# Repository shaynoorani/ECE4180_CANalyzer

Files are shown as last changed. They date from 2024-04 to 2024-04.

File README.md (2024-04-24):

# CANalyzer - Frugal CAN Line Analyzer with a C# GUI
- Brendan Bassett, Carl Cort, Eric Galluzi, Shayan Noorani, Tiancheng Zhao
- Throughout this page, there are links to the section of the main github repo [shaynoorani/ECE4180_CANalyzer](https://github.com/shaynoorani/ECE4180_CANalyzer/tree/main/functionaloverview.png) that correspond to the given component. Navigate to those to see the exact implementations

Team Picture

## Description
- CAN Line Analyzer for easy access to CAN data
- Simple C#-based GUI
   - Can filter based on CAN message ID
- Calculates and displays CAN Load

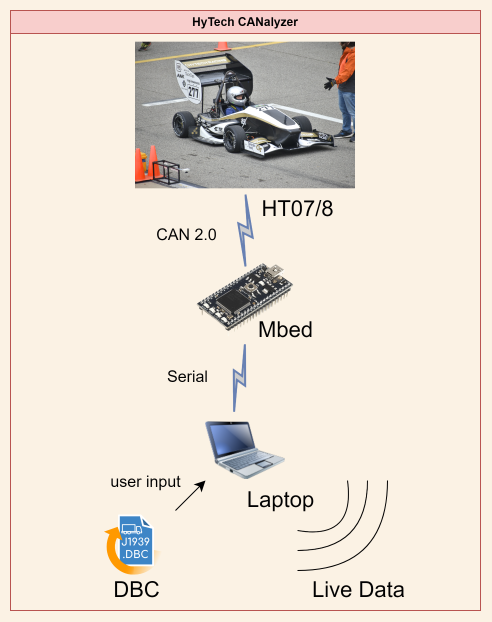
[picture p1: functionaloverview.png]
Team Picture


## Functionality Demo
[Team Picture](https://youtu.be/kEs1tA9cYeo?si=FgBFabkiXCYflOZx)

## Hardware
### Parts
- (x1) [Mbed](https://www.nxp.com/products/processors-and-microcontrollers/arm-microcontrollers/general-purpose-mcus/lpc1700-arm-cortex-m3/arm-mbed-lpc1768-board:OM11043)
- (x1) [CAN Transducer](https://www.trustedparts.com/en/part/texas-instruments/TCAN1051HDRQ1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)
- (x1) [SOP14 SMD-to-DIP Breakout](https://pmdway.com/products/sop14-tssop14-to-dip-adaptor-pcbs-10-pack)
  - Simply used as a breakout for the CAN Transducer for use on a breadboard
- [Breadboard](https://www.digikey.com/en/products/detail/universal-solder-electronics-ltd/SOLDERLESS%2520BREADBOARD%2520400/16819785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)
- Housing (optional)
- Male Molex Connector (optional)

### [Electronics](https://github.com/shaynoorani/ECE4180_CANalyzer/tree/main/schematic)

#### Wiring Diagram
Wiring Diagram

Note: the TCAN105 is the SMD CAN transducer itself and the wiring shown is for that device. However, the wires directly from the mbed go through the SOP14 breakout. The maping for the TCAN105 pins to the SOP14 pins are TCAN105(1-4) -> SOP14(1-4) and TCAN105(5-8) -> SOP14(11-14). This can be seen in the realworld image below.

#### Closeup of the Electronics
Closeup of the final electronics

### [Housing](https://github.com/shaynoorani/ECE4180_CANalyzer/tree/main/Housing) (Optional)
- The housing was developed to make the device more rugged for practical use but is not required for functionality
- As such, this section is presented to show not only our final design but also the measurements of the underlying device so that a different housing ould be developed if desired

#### Embedded Device Dimensions
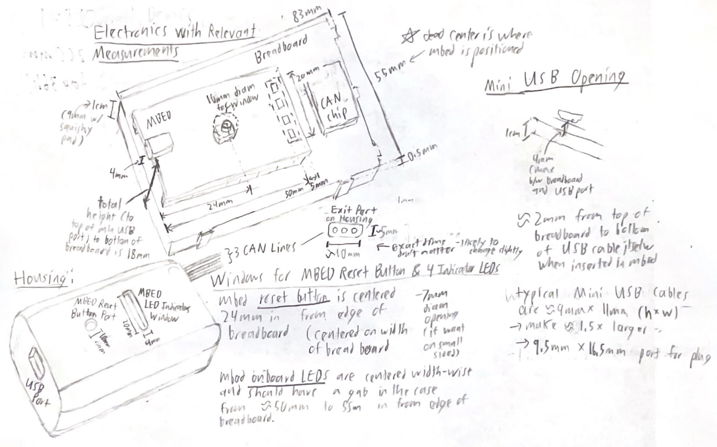
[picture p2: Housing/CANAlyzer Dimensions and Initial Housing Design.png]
Dimensions of relavent parts of the embedded device for designing the housing


*The CAN lines no longer come out as 3 lines but as one bundled wire that are terminated with a male molex connector since our car's CAN was accessible via a female molex

#### Final Housing Design
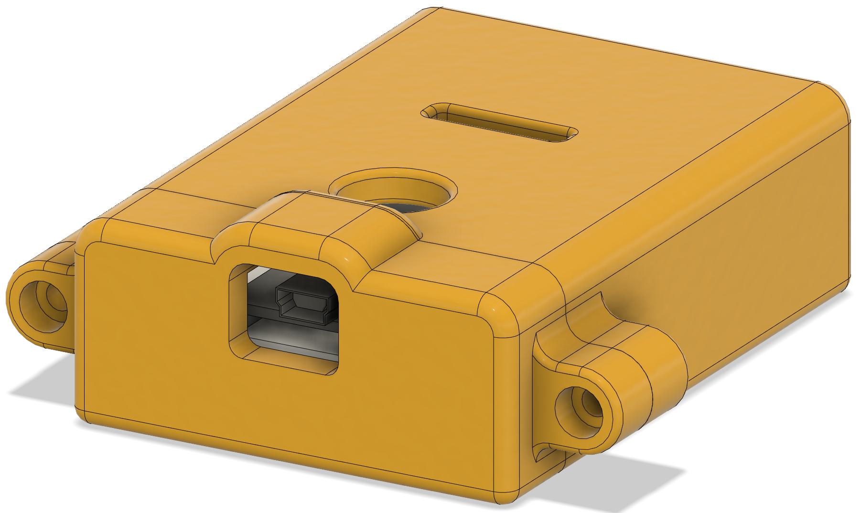
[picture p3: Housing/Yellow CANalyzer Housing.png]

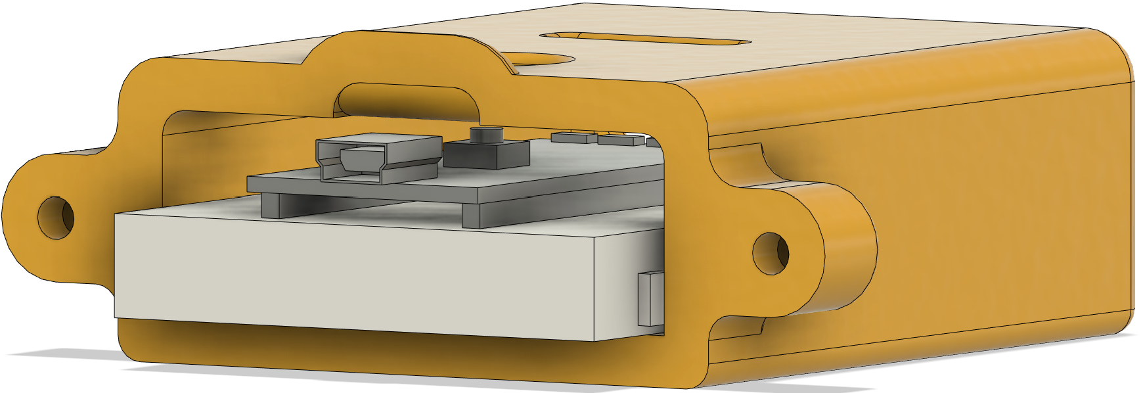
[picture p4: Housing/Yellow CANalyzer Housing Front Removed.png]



- Two 3D printed components (PLA on the Bambu printers at the HIVE)
- Front plate
  - Openning with ample clearance for varying size mini USB cables
- Main housing Body
  - Window for onboard Mbed indicator LEDs
  - Openning for Mbed reset button
  - Openning on back side for CAN lines
- Connected by M4 screws with a locking not pressure fit into the main housing side
  - Sturdy but also allows for replacement of Mbed or other components

## Software
- The Software is broken up into two key units: 1.) the Mbed-based CAN load calculator with CAN message passthrough and 2.) the C#-based DBC Message parser with the C# GUI
- The messages are first read across a serial connection from the CAN transducer to the mbed where they are either tallied to calculate CAN load or passed-through the USB virtual COM port to the computer for use in the DBC Parser and Gui
- The DBC parser reads the CAN messages sent by the mbed and packages them in structs that delineate the messages and segments the data into the message components
- Finally, the GUI displays the CAN message in an easily read format

### [Mbed - CAN Load Calculator & Message Passthrough](https://github.com/shaynoorani/ECE4180_CANalyzer/tree/main/main.cpp)
- Handles CAN passthrough using Serial communication with the CAN transducer and and the computer via the virtual COM port
- Also manages the logic for calculating the load in 10ms intervals
- The CAN load is calculated according to the following equation:

load

### [GUI & DBC Parser](https://github.com/shaynoorani/ECE4180_CANalyzer/tree/main/WindowsAppCanalyzer)
- The C# GUI & Parser reads in the serial data from the Mbed and differentiates between load messages and CAN messages sent as an ID + Data Frame
- Load is displayed on a progress bar at the top
- User is given the option to select a DBC, COM Port, and Baud Rate
- The program uses the [DBCParserLib](https://github.com/EFeru/DbcParser) to parse and display live decoded data.
- A filter option is included to facilitate analysis

## Usage
- Select COM Port
- Select Baud Rate
- Select DBC
- (Optional) Select ID Filter
- Connect/Run and Stop when necessary

gui

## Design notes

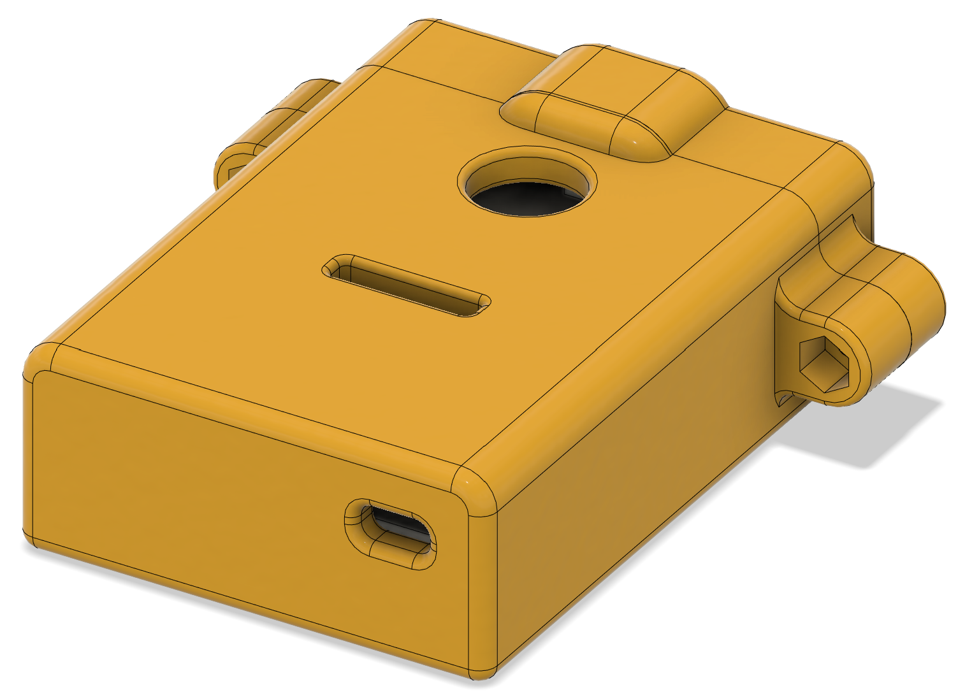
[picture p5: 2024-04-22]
Housing/Yellow CANalyzer Housing from Back.png

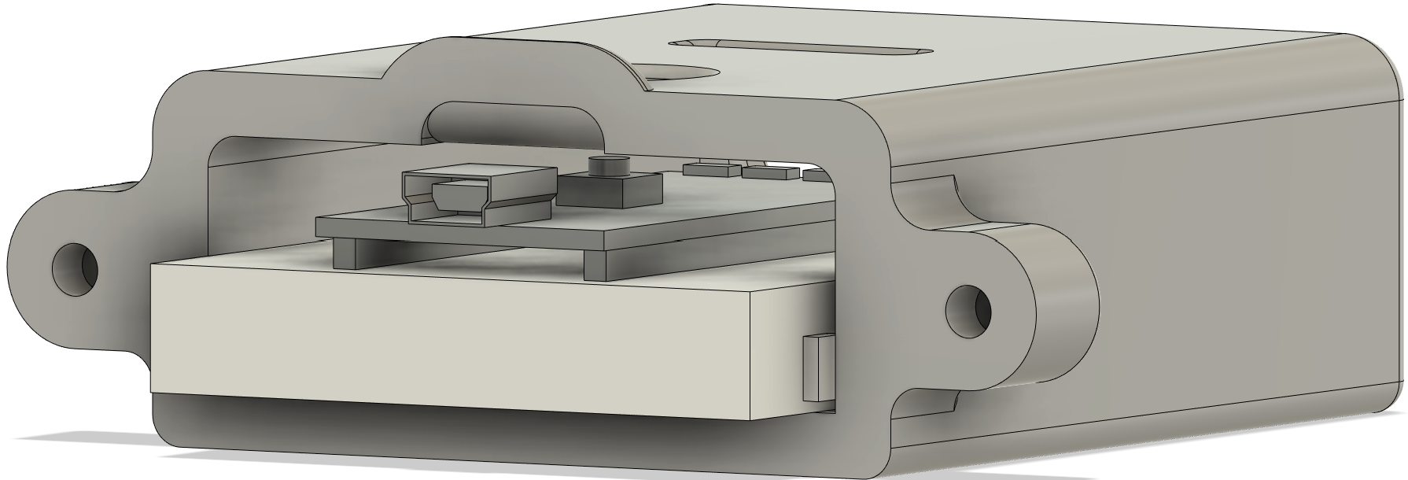
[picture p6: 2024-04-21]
Housing/CANAlyzer Housing Front Removed.png

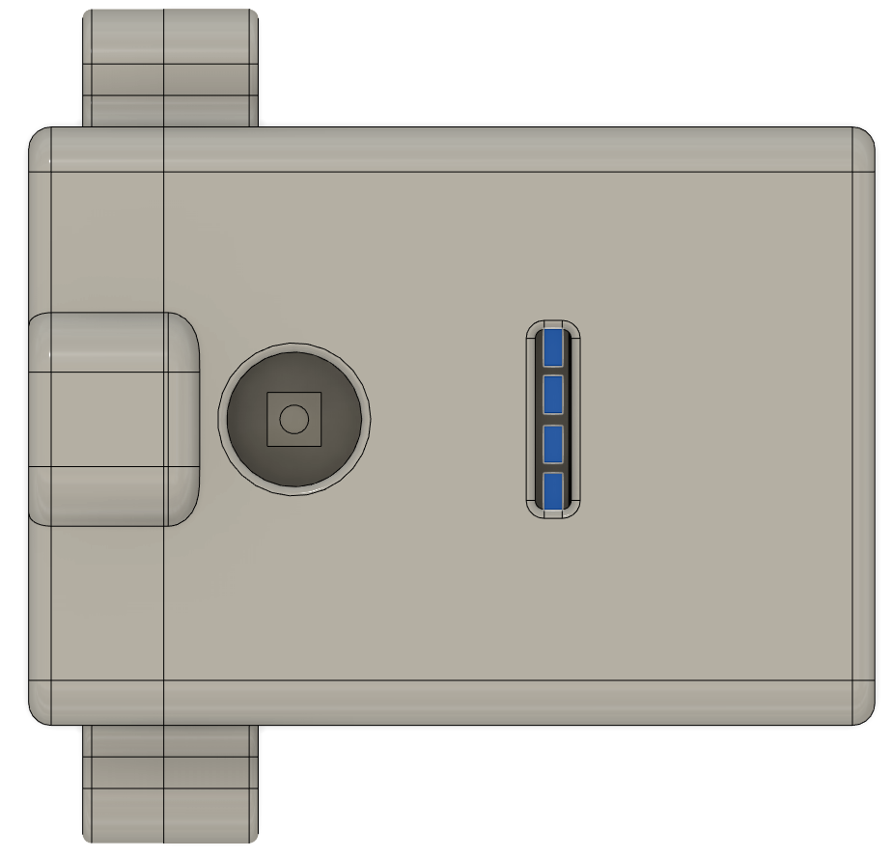
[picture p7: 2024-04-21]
Housing/CANAlyzer Housing Top.png

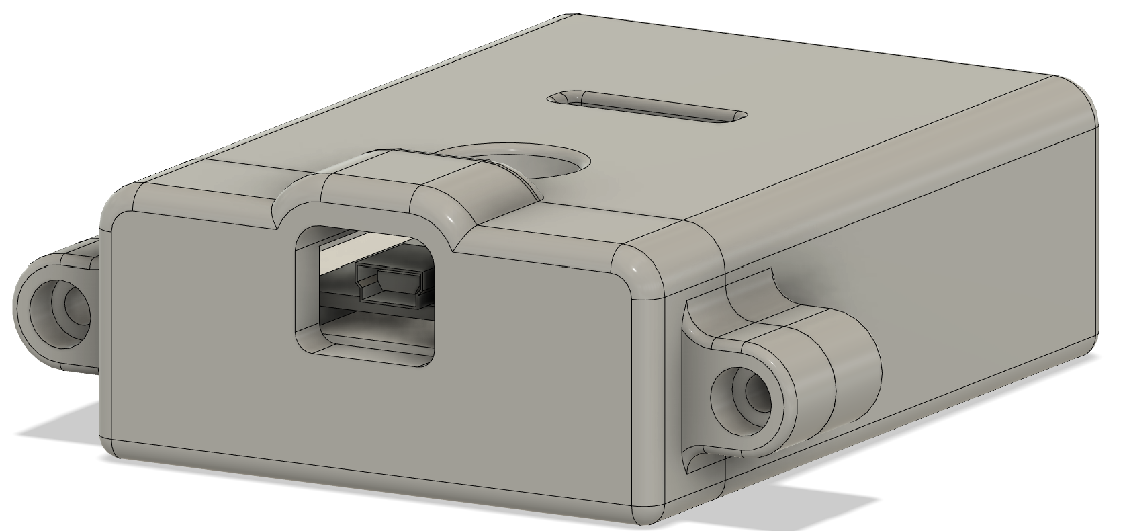
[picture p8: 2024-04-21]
Housing/CANAlyzer Housing.png

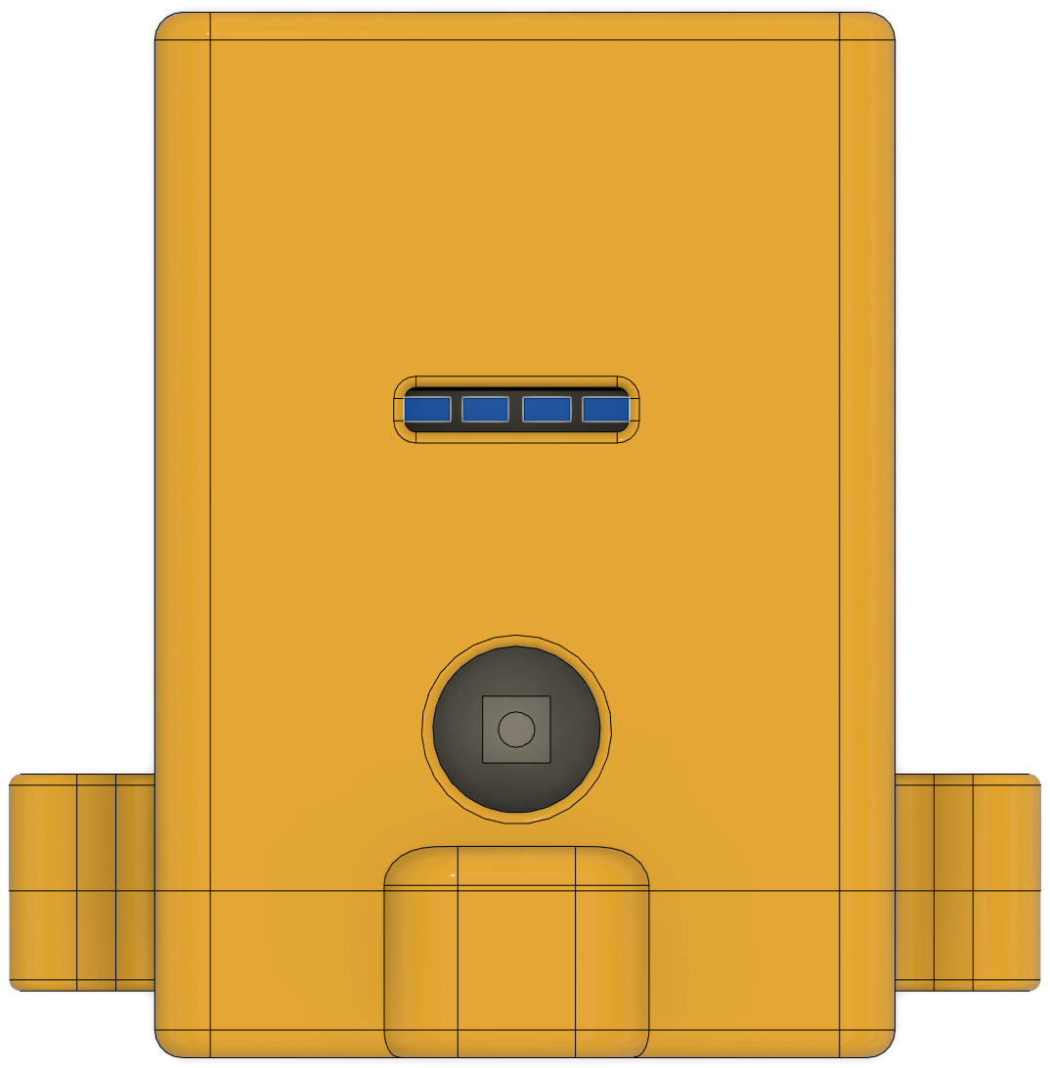
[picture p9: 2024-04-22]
Housing/Yellow CANalyzer Housing Top.png

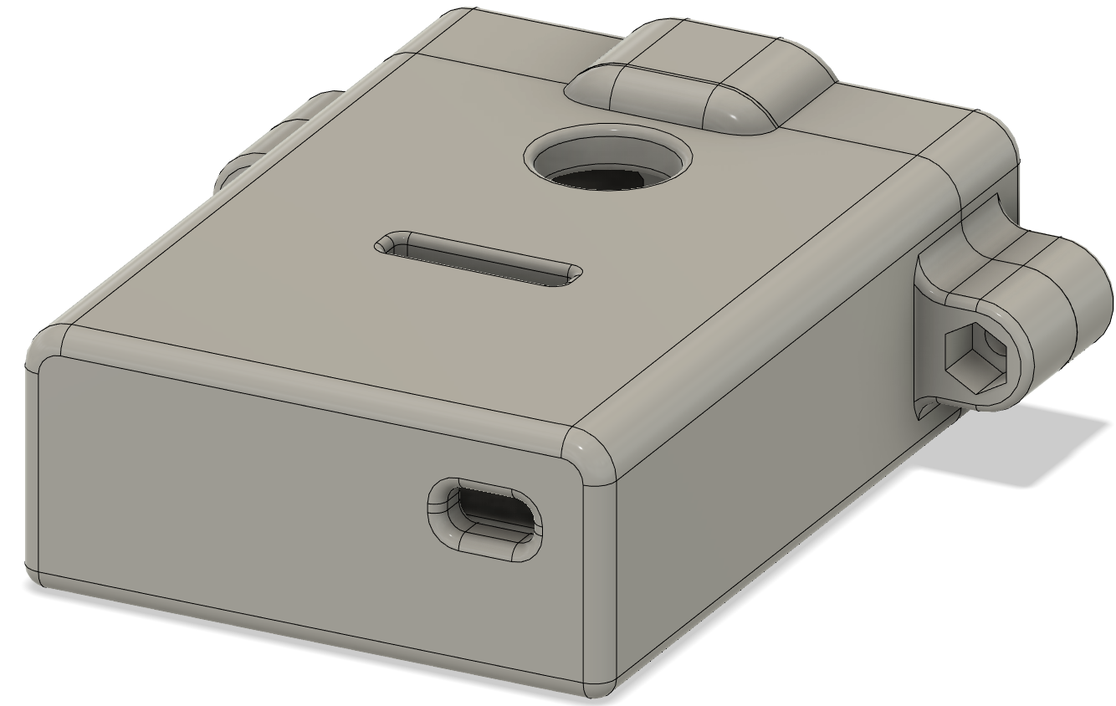
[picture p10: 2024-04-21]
Housing/CANAlyzer Housing from Back.png

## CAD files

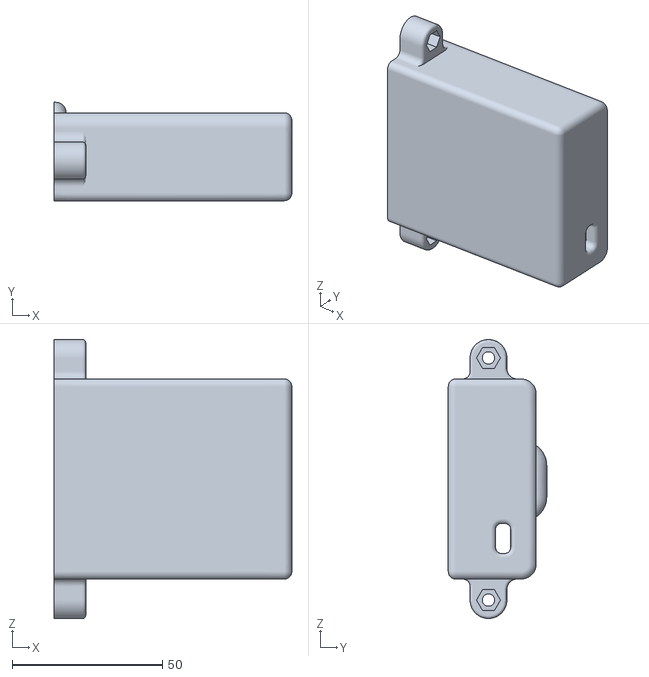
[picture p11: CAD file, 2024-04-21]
Housing/CANAlyzer_Main_Body.stl
79.0 x 32.8 x 92.7

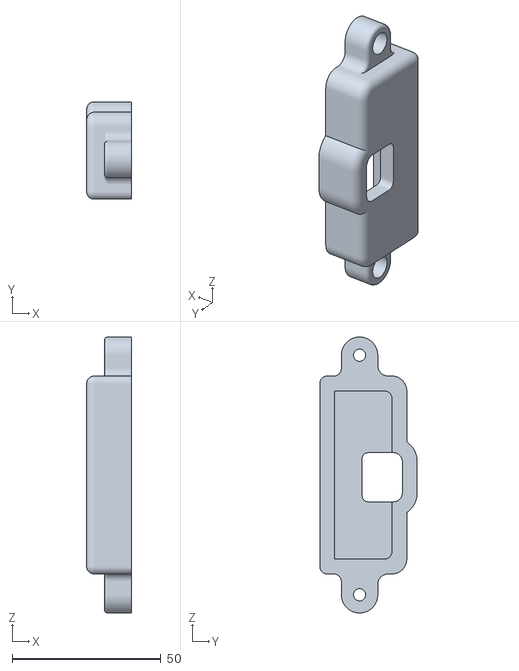
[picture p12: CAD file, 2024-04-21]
Housing/CANAlyzer_Front_Plate.stl
15.0 x 32.8 x 92.7

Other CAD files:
Housing/CANAlyzer Housing v7.f3z
Housing/Simple MBed and Breadboard v6.f3d

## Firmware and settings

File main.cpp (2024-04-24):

#include "mbed.h"
#define FREQ 500000

Serial      pc(USBTX, USBRX);
DigitalOut led1(LED1);
DigitalOut led2(LED2);
CAN         can(p30, p29);
CANMessage  msg;
Ticker can_load_tick;



class CAN_load_calculator{
private:
    bool calculating;
    Timer t;
    int t_prev;
    int t_now;

public:
    volatile int can_load;
    volatile int can_bits_counter;
    CAN_load_calculator(){
        calculating = false;
        t.stop();
        t_prev = 0;
        t_now = 0;
        can_load = 0;
        can_bits_counter = 0;
    }

    void send(){
        // pc.printf("tprev: %d\r\n", t_prev);
        // pc.printf("tnow: %d\r\n", t_now);
        pc.printf("The can load is: %0.2d %%\n ", can_load); // send over serial
        pc.printf("\r\n");
        reset_can_bits_counter();
    }

    void increment_can_bits_counter(int x){
        can_bits_counter += x;
    }

    void reset_can_bits_counter(){
        can_bits_counter = 0;
    }

    

};

CAN_load_calculator can_calc;  
void can_load_send() {
    can_calc.can_load =(int) 100 * ((double)can_calc.can_bits_counter / (5000.0));
}

int main()
{
    can.monitor(1);
    can.frequency(FREQ);
    

    int can_msg_counter = 0;
    pc.baud(115200);
    can_load_tick.attach(&can_load_send, .01); // send and measure can load every 0.5 second
    while(1) {
        // pc.printf("trying\n");
        if(can.read(msg)) {
            led1 = 1;
            if (msg.len){
                can_calc.increment_can_bits_counter(470);

                //print CAN msg to serial port if can_calc is not processing
                
                  pc.printf("%.3x!", msg.id);
                  for (int i = 7; i >= 0; i--) {
                    pc.printf("%.2x", msg.data[i]);
                  }
                  pc.printf("\r\n");
                

            }
            
        }
        
        led1 = 0;
        can_msg_counter++;

        if((can_msg_counter >= 100)){
           
            can_calc.send();
        }
        
    
        
    }
}

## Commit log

2024-04-21 Made the Housing folder - lazily making a folder
2024-04-21 Added the files relating to the CANAlyzer housing
    [CANAlyzer Housing v7.f3z, CANAlyzer_Front_Plate.stl, CANAlyzer_Main_Body.stl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]
2024-04-22 hardware schematic
    [schematic.kicad_pcb, schematic.kicad_sch]
2024-04-22 Made the Housing Yellow to Reflect the Printed One
2024-04-22 Added molex connector to hardware section
